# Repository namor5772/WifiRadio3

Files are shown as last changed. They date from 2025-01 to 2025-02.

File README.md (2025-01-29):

# Internet Radio

Here we describe the design, construction, programming and operation of an internet radio with a minimal one button interface based on a Raspberry Pi.
This is a relatively minor variation to WifiRadio2 (also available in this repository).
It uses a smaller older type of Raspberry Pi with the setup is more comprehensively documented.
There is a new 3D printed case that encompasses both the Raspberry Pi and the interface circuit board.

There are 7 available radio stations. One scrolls through them by successively pressing the tactile switch. The station number selected is diplayed in binary by three red 5mm LEDs. When all three LEDs are off then no station is playing (number 0). When the radio is powered off (by removing power to the Raspberry Pi) the currently streaming station is saved so that when the radio is powered on later that station resumes streaming.

## Physical design

The TinyCad design file [WifiRadio2.dsn](Hardware/WifiRadio2.dsn) for the interface circuitry is displayed below:
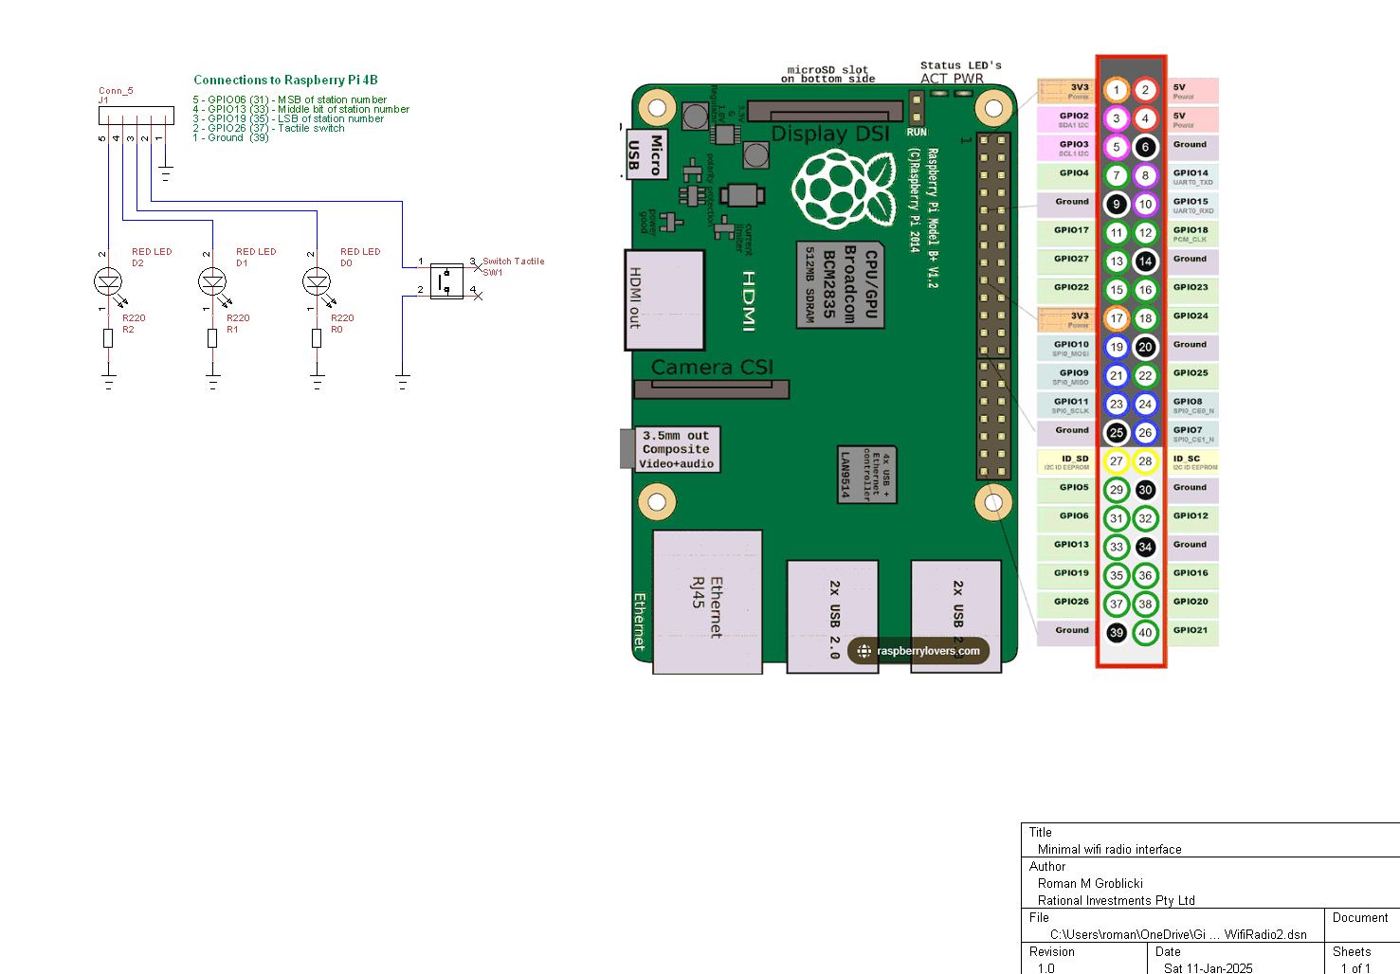
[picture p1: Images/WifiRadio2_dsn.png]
WifiRadio2.net


The resulting VeeCad file [WifiRadio2.per](Hardware/WifiRadio2.per) is displayed below:

It is obtained from the Netlist file [WifiRadio2.net](Hardware/WifiRadio2.net) generated from WifiRadio2.dsn (displayed above).
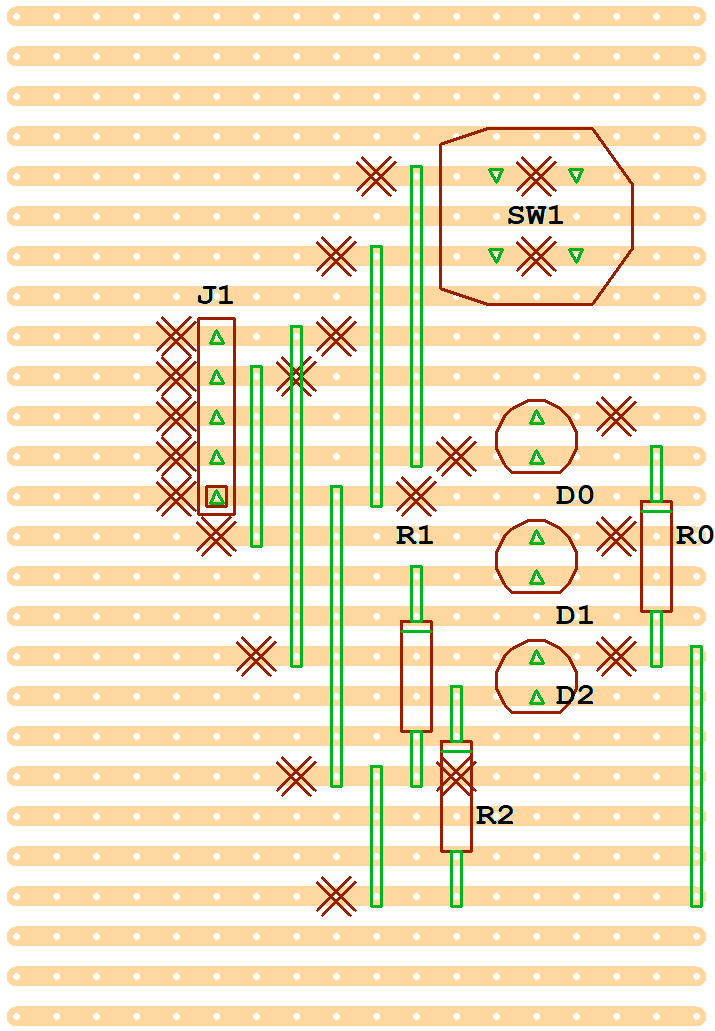
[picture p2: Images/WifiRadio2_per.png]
WifiRadio2.per


This is what the completed interface board looks like:
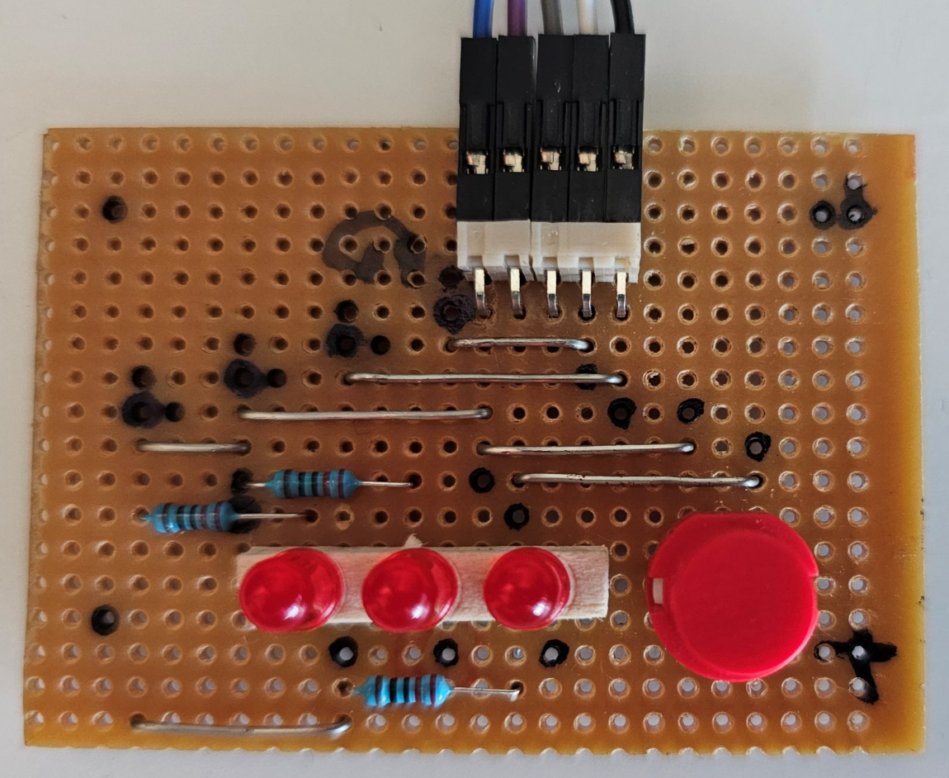
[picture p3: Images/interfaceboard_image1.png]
interfaceboard image1

Note that the LEDs are offset from the circuit board by 5mm using an appropriate piece of balsawood.
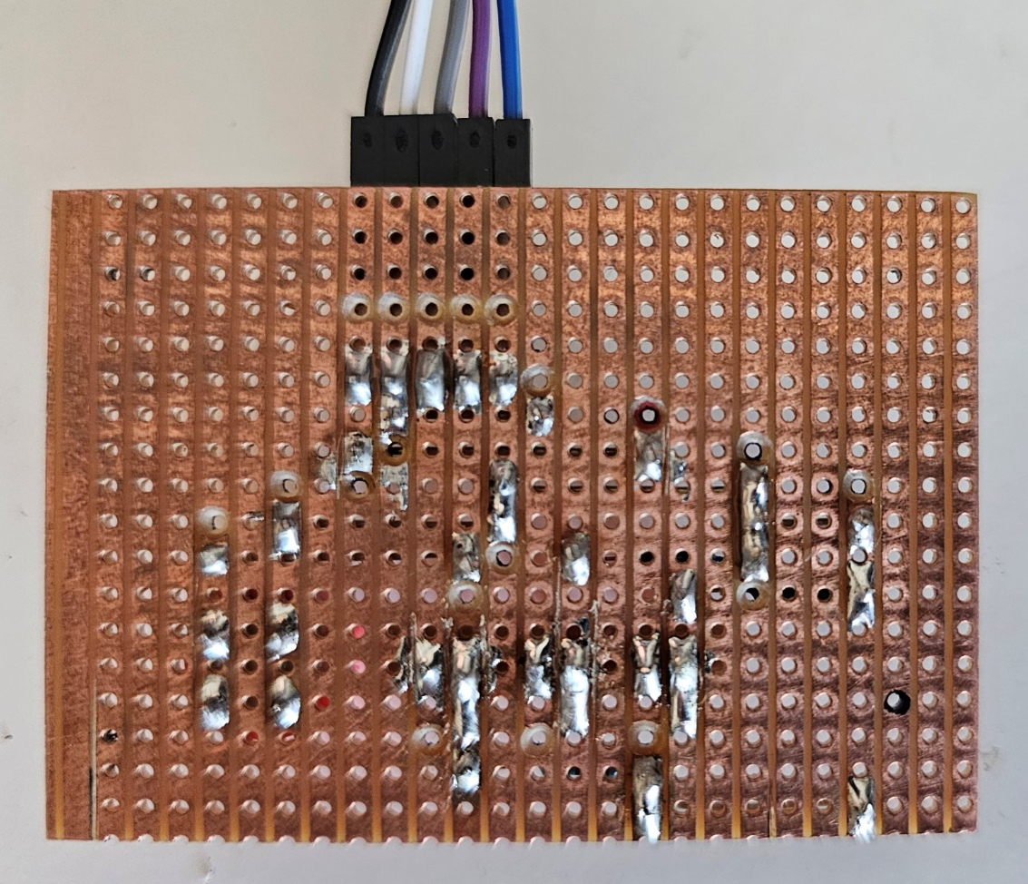
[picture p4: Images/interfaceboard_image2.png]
interfaceboard image2


## Enclosure

The interface circuit is placed in a custom 3D printed enclosure which is secured on top of the case that houses the Raspberry Pi. 5 wires connect the interface circuit to the Raspberry Pi. This is the internet radio to which stereo USB powered 3.5m audio speakers must be attached (to the underlying Raspberry Pi).

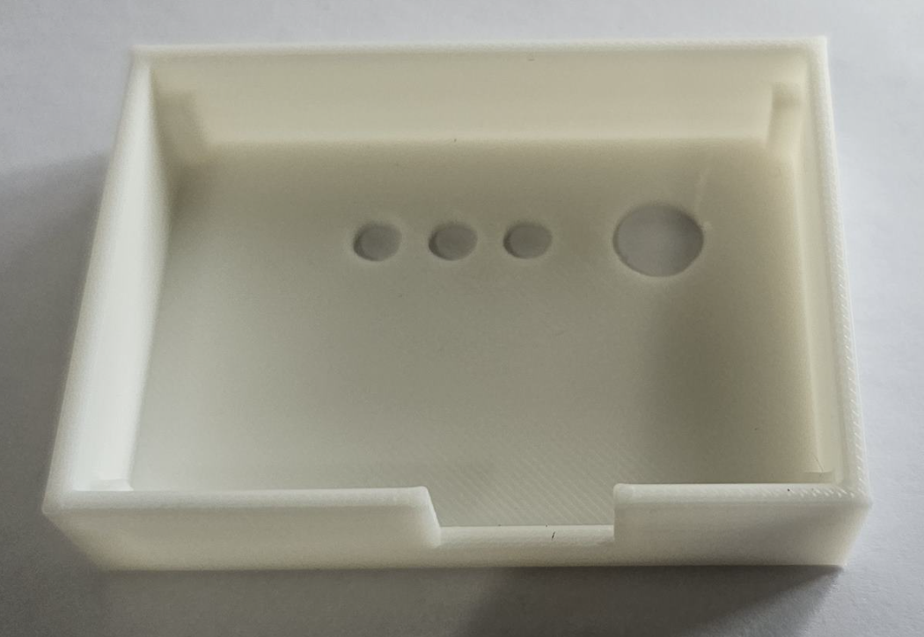
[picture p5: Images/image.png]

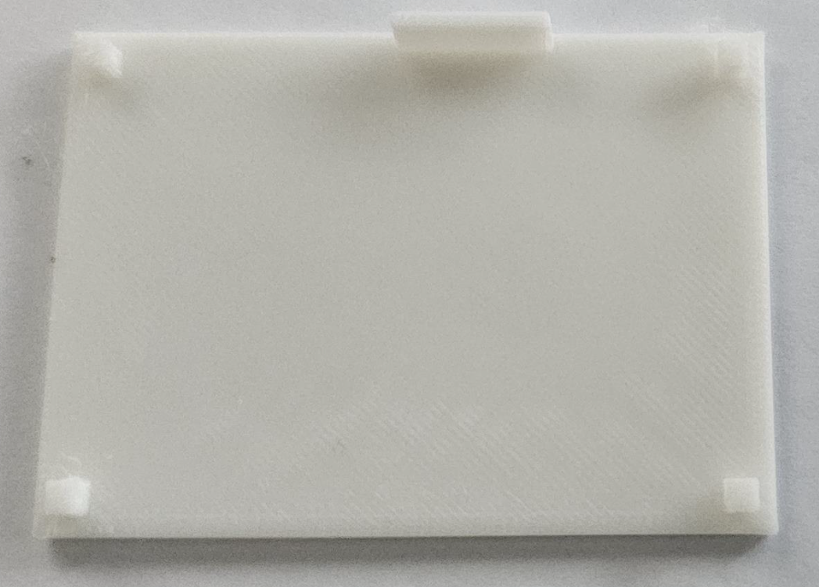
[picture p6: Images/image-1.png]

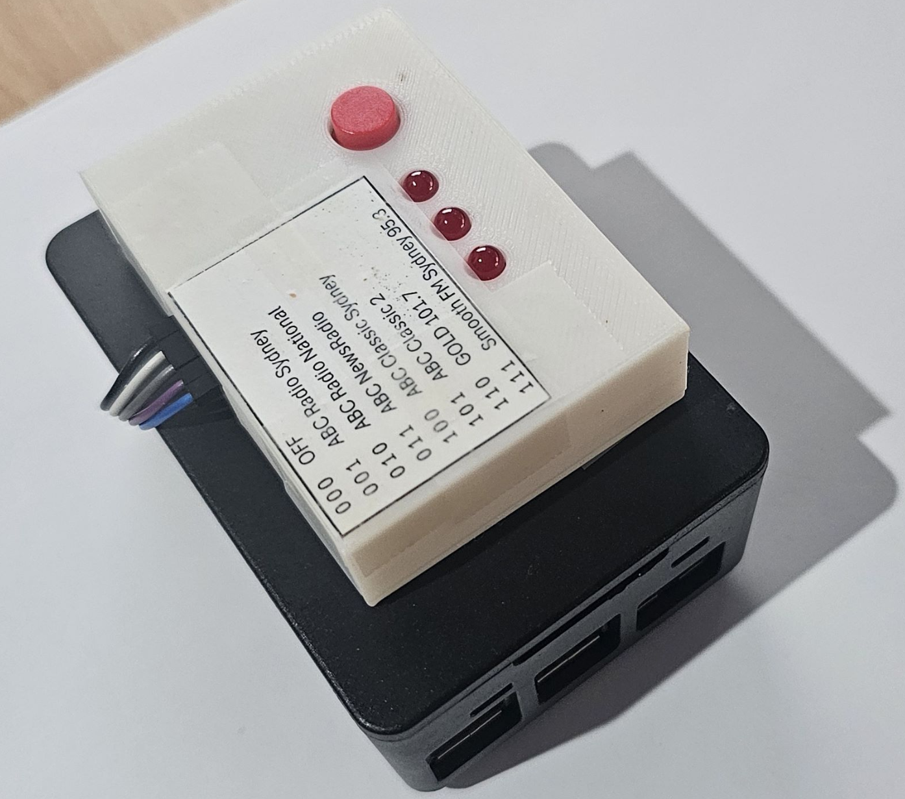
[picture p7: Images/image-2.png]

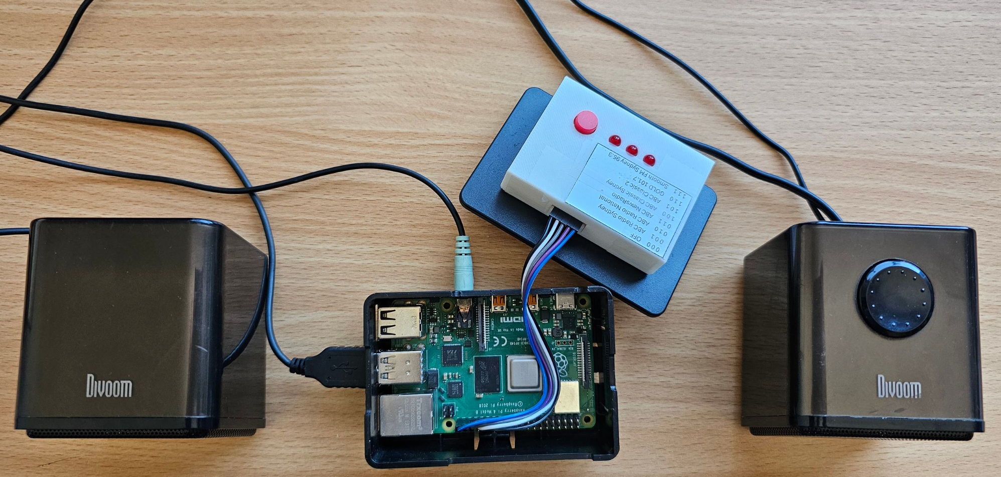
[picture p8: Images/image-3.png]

The case was designed using Blender.

The top of the case is in [WifiRadio2_BoxTop.blend](Hardware/WifiRadio2_BoxTop.blend), while the bottom is in [WifiRadio2_BoxBottom.blend](Hardware/WifiRadio2_BoxBottom.blend). To view or edit these files open them with the Blender 4.3 App in Windows 11.

To be able to 3D print the enclosure these files must be exported from the Blender App as [WifiRadio2_BoxTop.stl](Hardware/WifiRadio2_BoxTop.stl) and [WifiRadio2_BoxBottom.stl](Hardware/WifiRadio2_BoxBottom.stl) respectively.

Finally these *.stl files must be opened into the Crealty Print 6.0 Windows 11 App which creates the [WifiRadio2_BoxTop.3mf](Hardware/WifiRadio2_BoxTop.3mf) and [WifiRadio2_BoxBottom.3mf](Hardware/WifiRadio2_BoxBottom.3mfl) respectively. These contain the type of printer needed and other details of the print and are the basis for creating (by File => Export => Export Gcode...) the *.gcode files [WifiRadio2_BoxTop.gcode](Hardware/WifiRadio2_BoxTop.gcode) and [WifiRadio2_BoxBottom.gcode](Hardware/WifiRadio2_BoxBottom.gcode) respectively. These are the actual files used by the 3D Printer to do the actual printing! The files saved here are for the Crealty Ender-3 V3 SE printer with default setting for Hyper PLA.

If you have a different 3D printer you can still use the *.stl files but you will have to generate the *.gcode files yourself.

## Raspberry Pi setup

I have used a Raspberry Pi Model B Rev1.2 with 4Gb RAM, running Raspbian GNU/Linux 12 (bookworm) on a 32Gb SD card (which you will have to image).
It is configured to Boot To Desktop with Auto login, with only the Remote GPIO enabled.

Install Python3 and idle3 as well as vlc, all of which reside in the directory /usr/bin/.
In the directory /home/{username}/.config/autostart/ create a file autovlc.desktop with the contents:

```terminal
[Desktop Entry]
Type=Application
Exec=/usr/bin/idle -r /home/roman/GitHub/WifiRadio2/Radio5.py
```

This way of running the script via autostart in the GUI is because I tried to run it after boot in the Command Line Interface (CLI), however I could not make this work due to some privilage issues which made vlc unable to execute. This would have been more efficient and elegant but I just wanted to make it work.

In the directory /home/{username}/GitHub/WifiRadio2/ which you need to create place the python script Radio5.py (detailed below). You will also need to make the Wifi network automatically connect to an available access point by discovering it and inputting its password. if you move the location of this internet radio you will need to setup another wifi connection by accessing the Raspbewrry Pi's GUI with an attached mouse, keyboard and screen! 

## Software

The radio is implemented in software by a python script [Radio5.py](Radio5.py) that auto starts through the Python IDLE shell when the the GUI becomes active. The audio streaming uses cvlc. A valid wifi connection is assumed to be available and automatically enabled when the Raspberry Pi is powered on.

```python
# all part of the Python standard libraries, with RPI.GPIO pre installed as part of the Raspian os
import subprocess
import time
import RPi.GPIO as GPIO
import os;    

# Get the directory where the script is located
script_directory = os.path.dirname(os.path.abspath(__file__))

# Create the full filepath to the saved radio station file
filename = 'savedRadioStation.txt'
filepath = os.path.join(script_directory, filename)
print(f'The file {filepath} stores the last streamed station number.')

# Use BCM GPIO numbering 
GPIO.setmode(GPIO.BCM)

# Define the 4 Raspberry Pi pins that go to the interface circuit board
# Ground is not included
button_pin = 26
led0_pin = 19
led1_pin = 13
led2_pin = 6

# Setup the pins
GPIO.setup(button_pin, GPIO.IN, pull_up_down=GPIO.PUD_UP)
GPIO.setwarnings(False)
GPIO.setup(led0_pin, GPIO.OUT)
GPIO.setup(led1_pin, GPIO.OUT)
GPIO.setup(led2_pin, GPIO.OUT)

# setup the leds to be initially all off
GPIO.output(led0_pin,GPIO.LOW)
GPIO.output(led1_pin,GPIO.LOW)
GPIO.output(led2_pin,GPIO.LOW)

# 2D array of radio station information in [short name, long name, url] format
# clearly this can be varied if you wish to listen to different 7 stations
aStation = [
    ["2LRW","ABC Radio Sydney","https://live-radio01.mediahubaustralia.com/2LRW/mp3/"],
    ["5LRW","ABC Radio National","https://live-radio01.mediahubaustralia.com/2RNW/mp3/"],
    ["PBW","ABC NewsRadio","https://live-radio01.mediahubaustralia.com/PBW/mp3/"],
    ["2FMW","ABC Classic Sydney","https://live-radio01.mediahubaustralia.com/2FMW/mp3/"],
    ["FM2W","ABC Classic 2","https://live-radio01.mediahubaustralia.com/FM2W/mp3/"],
    ["WSFM","GOLD 101.7","https://playerservices.streamtheworld.com/api/livestream-redirect/ARN_WSFM.mp3"],
    ["SMOOTH953","Smooth FM Sydney 95.3","https://playerservices.streamtheworld.com/api/livestream-redirect/SMOOTH953.mp3"]
]

# some utility global variables
vlc_path = "/usr/bin/cvlc" # full path to cvlc, it is installed together with vlc
Running = False # flag True if radio station is streaming
nStation = 0 # station number (0 is the "no radio streaming" station)
startup = True # True when radio initially powered up 

print("Radio stream interface")

while True:

    if ((GPIO.input(button_pin) == GPIO.LOW) or (startup)):
        time.sleep(0.2) # pathetic debouncing code

        if (startup):
            # load saved station number from file when radio powered up
            try:
                with open(filepath, 'r') as file:
                    nStation = int(file.read())
            except FileNotFoundError:
                print(f'Error: The file {filepath} does not exist.')
                nStation = 0
        else:
            # increment station number modulo 8 when button pressed
            if nStation == 7:
                nStation = 0
            else:
                nStation = nStation +1

            # save station number to file (if radio powered off when playing this station)
            with open(filepath, 'w') as file:
                file.write(str(nStation))

        # display the station number in binary
        bit0 = (nStation >> 0) & 1 # LSB
        bit1 = (nStation >> 1) & 1 # middle bit
        bit2 = (nStation >> 2) & 1 # MSB
        GPIO.output(led0_pin,bit0)
        GPIO.output(led1_pin,bit1)
        GPIO.output(led2_pin,bit2)
        print("Button pressed, Station: ",nStation)    

        if nStation > 0:
            stream_url = aStation[nStation-1][2]
            stream_longName = aStation[nStation-1][1]

        if nStation == 0:
            if Running:    
                process.terminate()
            Running = False
            print("No streaming")

        elif nStation == 1:
            # started new process, but no need to terminate previous one since already terminated
            process = subprocess.Popen([vlc_path, stream_url])
            Running = True
            print("Started streaming radio station: " + stream_longName)

        else:
            if (not startup):
                # need to terminate current process, before starting new one
                process.terminate()
                
            process = subprocess.Popen([vlc_path, stream_url])
            Running = True
            print("Started streaming radio station: " + stream_longName)

        startup = False   

```
## List of parts

Pricing and availability as of 26-Jan-2025. Total cost is $250.57, but clearly some of the items will be usable in many other projects or you will already have them. The pro rata cost is __$209.11__

You will also need a soldering iron and solder, some two sided tape for attaching the circuit enclosure on top of the Raspberry Pi case as well as a printer to print the station legend for taping/sticking to the top of the enclosure. 

| Qty | Product | Description | AUD Cost | Comment | Designator |
| --- | --- | --- | --- | --- | --- |
| 1 | [RPI4-MODBP-4GB](https://au.element14.com/raspberry-pi/rpi4-modbp-4gb/raspberry-pi-4-model-b-4gb/dp/3051887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) | SBC, [Raspberry Pi4 B 4GB](Images/RPI4B.png), BCM2711, ARM Cortex-A72, 4GB RAM, MicroSD, Linux, Wifi, 2x micro HDMI | $92.65 | The brains of this project with this [datasheet](Hardware/4170044.pdf)  | connected via J1 |
| 1 | [XC4992](https://jaycar.com.au/p/XC4992) | 32GB Class 10 microSDHC [Card](Images/Card.png) | $12.95 | For Raspberry Pi OS and storage | |
| 1 | [PH-102475](https://raspberry.piaustralia.com.au/products/highpi-raspberry-pi-4-model-b-case) | HighPi Raspberry Pi 4 Model B [Case](Images/Case.png) | $32.12 | could use other cases | |
| 1 | [HP9544](https://jaycar.com.au/p/HP9544) | PC Boards Vero Type [Strip](Images/Strip.png) - 95mm x 305mm | $15.50 | Contains the circuit | $4.00 cost used|
| 3 | [ZD0150](https://jaycar.com.au/p/ZD0150) | Red 5mm [LED](Images/LED.png) 8mcd Round Diffused | $1.20 | indicate status in binary | D0, D1, D2 |
| 1 | [SP0720](https://jaycar.com.au/p/SP0720) | Red Snap Action Keyboard [Switch](Images/Switch.png) - PCB Mount | $1.45 | The only input item | SW1 |
| 1 | [RR0556](https://jaycar.com.au/p/RR0556) | 220 Ohm 0.5 Watt Metal Film [Resistors](Images/Resistor.png) - Pack of 8 (only need 3) | $0.85 | Current limiting for LEDs | R0, R1, R2 - $0.32 cost used|
| 1 | [HM3422](https://jaycar.com.au/p/HM3422) | 2 Pin 0.1in 90 Degree Locking [Header](Images/Header2.png) - 2.54mm Pitch - Single | $0.30 | connector to RPi | part of J1 |
| 1 | [HM3423](https://jaycar.com.au/p/HM3423) | 3 Pin 0.1in 90 Degree Locking [Header](Images/Header3.png) - 2.54mm Pitch - Single | $0.40 | connector to RPi | part of J1 |
| 1 | [WW4030](https://jaycar.com.au/p/WW4030) | Tinned Copper [Wire](Images/Wire.png) - 100 gram Roll | $19.95 | for wiring up above Vero board | $0.80 cost used|
| 1 | [WC6026](https://jaycar.com.au/p/WC6026) | 150mm Socket to Socket Jumper [Leads](Images/Leads.png) - 40 Piece | $11.75 | 5 wires to connect Vero Board to Raspberry Pi | connects to J1 - $1.47 cost used|
| 1 | [XC5191](https://jaycar.com.au/p/XC5191) | USB Powered PC [Speakers](Images/Speakers.png) | $19.75 | Any if USB powered & 3.5mm input | |
| 1 | [MP3449](https://jaycar.com.au/p/MP3449) | Mains USB Mini Power [Adaptor](Images/Adaptor.png) - 2.4A | $26.95 | to Power Raspberry Pi | |
| 1 | [WC7900](https://jaycar.com.au/p/WC7900) | USB Type-C to USB 2.0 A Male [Cable](Images/Cable.png) 1.8m | $14.75 | to Power Raspberry Pi | |

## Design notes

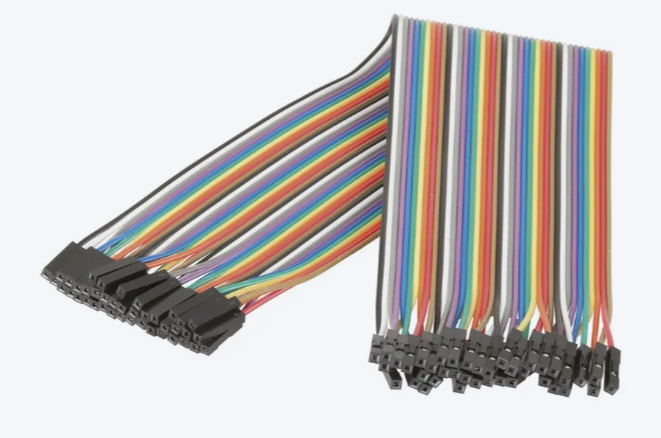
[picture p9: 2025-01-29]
Images/Leads.png

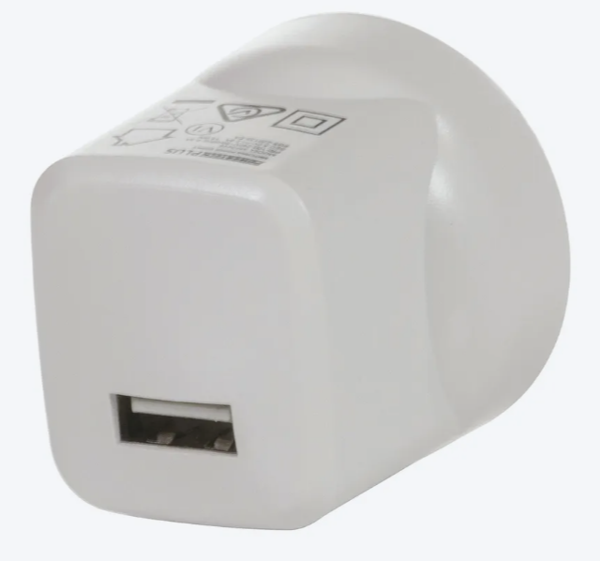
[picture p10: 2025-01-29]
Images/Adaptor copy.png

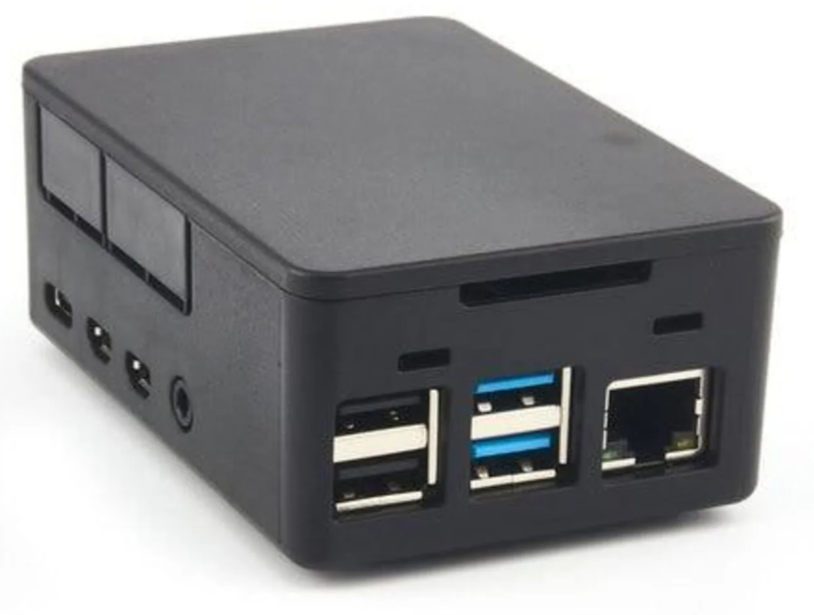
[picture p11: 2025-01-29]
Images/Case copy.png

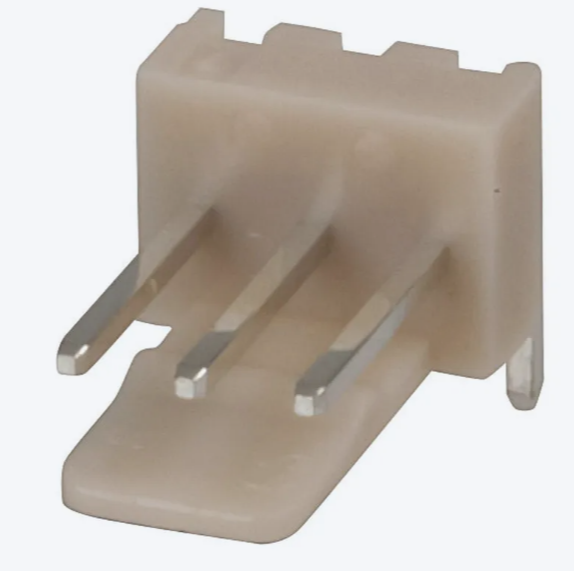
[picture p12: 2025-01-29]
Images/Header3.png

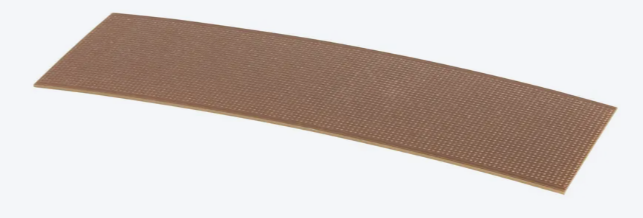
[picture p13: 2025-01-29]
Images/Strip.png

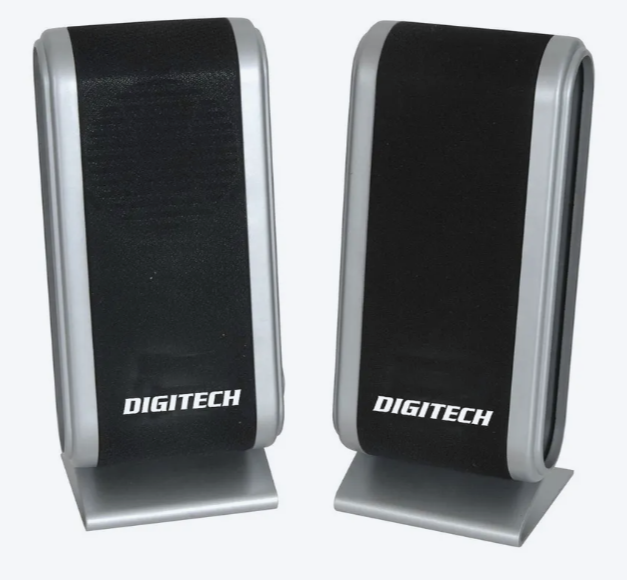
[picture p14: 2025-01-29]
Images/Speakers.png

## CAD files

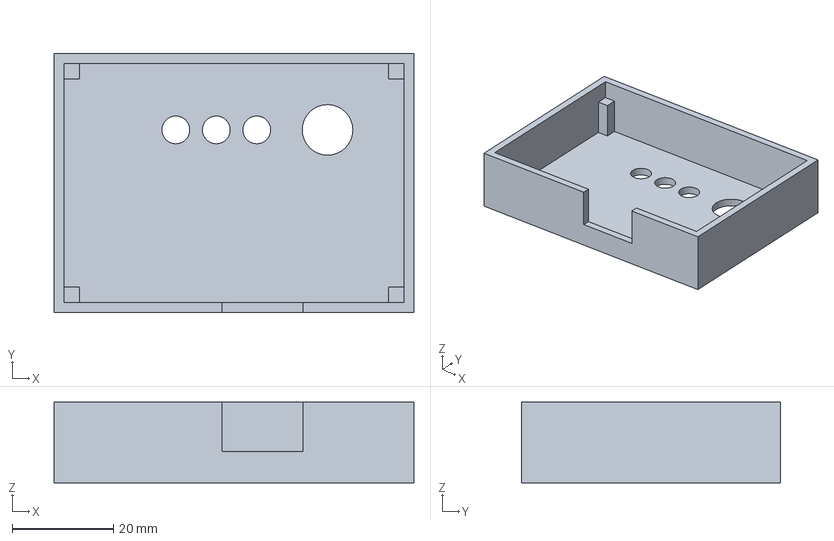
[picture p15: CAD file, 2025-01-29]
Hardware/WifiRadio2_BoxTop.3mf
71.2 x 51.2 x 16.0 mm

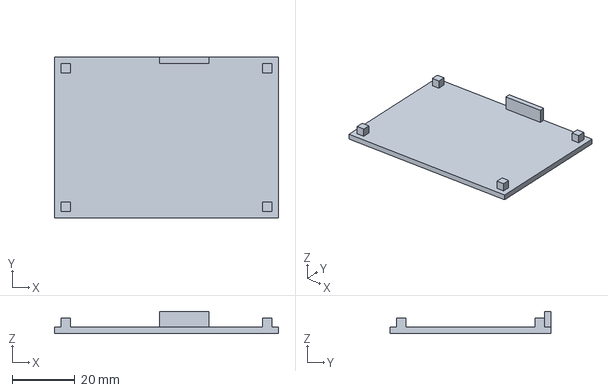
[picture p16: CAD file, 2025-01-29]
Hardware/WifiRadio2_BoxBottom.3mf
71.2 x 51.2 x 7.00 mm

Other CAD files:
Hardware/WifiRadio2_BoxBottom.blend
Hardware/WifiRadio2_BoxBottom.stl
Hardware/WifiRadio2_BoxTop.blend
Hardware/WifiRadio2_BoxTop.stl

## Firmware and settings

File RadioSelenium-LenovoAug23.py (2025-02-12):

import subprocess
import inspect
import tkinter as tk
import time
import urllib.request
import requests

from PIL import Image, ImageTk
from tkinter import ttk
from bs4 import BeautifulSoup
from selenium import webdriver
from selenium.webdriver.firefox.options import Options
from selenium.webdriver.common.by import By
from selenium.common.exceptions import NoSuchElementException
from selenium.webdriver.common.keys import Keys
from selenium.webdriver.common.action_chains import ActionChains
from selenium.webdriver.support.ui import WebDriverWait
from selenium.webdriver.support import expected_conditions as EC

# Create an instance of FirefoxOptions
firefox_options = Options()
#firefox_options.add_argument("-headless")  # Ensure this argument is correct
browser = webdriver.Firefox(options=firefox_options)

image_path = r"C:\Users\grobl\OneDrive\GitRepos\WifiRadio3\Images\logo.png"
image2_path = r"C:\Users\grobl\OneDrive\GitRepos\WifiRadio3\Images\presenter.jpg"



def Suck_ABC(br,sPath):
    br.refresh()
    br.get(sPath)
    time.sleep(3)
    be = br.find_element(By.TAG_NAME, 'body')
    be.send_keys(Keys.TAB)
    be.send_keys(Keys.ENTER)
    be.send_keys(Keys.TAB)
    be.send_keys(Keys.TAB)

    be.send_keys(Keys.TAB)
    be.send_keys(Keys.TAB)
    be.send_keys(Keys.TAB)
    be.send_keys(Keys.TAB)
    be.send_keys(Keys.TAB)
    be.send_keys(Keys.TAB)
    be.send_keys(Keys.TAB)
    be.send_keys(Keys.TAB)
    be.send_keys(Keys.TAB)
    be.send_keys(Keys.TAB)
    be.send_keys(Keys.TAB)
    be.send_keys(Keys.TAB)
    be.send_keys(Keys.TAB)
    be.send_keys(Keys.TAB)
    be.send_keys(Keys.TAB)

    # Use JavaScript to get the currently focused (active) element
    active_element = br.execute_script("return document.activeElement")

    # Retrieve various attributes of the active element
    element_tag_name = active_element.tag_name
    element_id = active_element.get_attribute('id')
    element_class = active_element.get_attribute('class')
    element_name = active_element.get_attribute('name')
    element_value = active_element.get_attribute('value')
    element_inner_html = active_element.get_attribute('innerHTML')

    # Parse the innerHTML with BeautifulSoup
    soup = BeautifulSoup(element_inner_html, 'lxml')

    # Find all elements with data-component="KeyboardFocus"
    focused_elements = soup.find_all(attrs={"data-component": "KeyboardFocus"})

    # Extract and print the text content of these elements
    for element in focused_elements:
        print(element.text)

    be.send_keys(Keys.ENTER)
    time.sleep(1)
    be = br.find_element(By.TAG_NAME, 'body')

    for _ in range(14):
        be.send_keys(Keys.TAB)
    be.send_keys(Keys.ENTER)




# START ***** Functions that stream radio stations *****

# ALL GOOD
def Radio1(br,Num,sPath):
    br.get(sPath)
    time.sleep(1)
    be = br.find_element(By.TAG_NAME, 'body')
    for _ in range(Num):
        be.send_keys(Keys.TAB)
    be.send_keys(Keys.ENTER)
    time.sleep(1)
    # Find song details
    ht = be.get_attribute('innerHTML')
    soup = BeautifulSoup(ht, 'lxml')
    fe = soup.find(attrs={"class": "playingNow"})
    if fe is not None:
        fe2 = fe.get_text(separator="*", strip=True)
    else:
        fe2 = "No specific item playing"
    return fe2

# ALL GOOD
def Radio2(br,Num,sPath):
    br.get(sPath)
    time.sleep(1)
    be = br.find_element(By.TAG_NAME, 'body')
    for _ in range(3):
        be.send_keys(Keys.TAB)
    be.send_keys(Keys.ENTER)
    for _ in range(4):
        be.send_keys(Keys.UP)
    for _ in range(Num):
        be.send_keys(Keys.DOWN)
    be.send_keys(Keys.ENTER)
    for _ in range(3):
        be.send_keys(Keys.TAB)
    be.send_keys(Keys.ENTER)
    time.sleep(1)

  # get station logo
    # Display the station logo as given in the image_path2 variable below
    image_path2 = r"C:\Users\grobl\OneDrive\GitRepos\WifiRadio3\Images\ABC_Radio_National.png"
    image = Image.open(image_path2)
    scaled_image = image.resize((90, 90))  # Adjust the size as needed
    photo = ImageTk.PhotoImage(scaled_image)
    label.config(image=photo)
    label.image = photo  # Keep a reference to avoid garbage collection

  # get presenter image
    img2_element = be.find_element(By.XPATH, '/html/body/div[1]/div/div/div/main/div[1]/div/div/header/div/div/img')
    img2_url = img2_element.get_attribute("src")
    urllib.request.urlretrieve(img2_url, image2_path)

    # Display the station presenter as given in the image2_path global variable
    image2 = Image.open(image2_path)
    width2, height2 = image2.size;
    print(f"width: {width2}, height: {height2}")
    scaled_image2 = image2.resize((int(135*width2/height2), 135))  # Adjust the size as needed
    photo2 = ImageTk.PhotoImage(scaled_image2)
    label2.config(image=photo2)
    label2.image = photo2  # Keep a reference to avoid garbage collection
    label2.place(x=339, y=107)  # Adjust the position
    
  # Find stream details
    ht = be.get_attribute('innerHTML')
    soup = BeautifulSoup(ht, 'lxml')
    fe = soup.find(attrs={"class": "view-live-now popup"})
    if fe is not None:
        fe2 = fe.get_text(separator="*", strip=True)
    else:
        fe2 = "No specific item playing"
  # Remove irrelevant info, starting with [*.*More]
    sub = "*.*More"
    pos = fe2.find(sub)
    if pos != -1:
        fe2 = fe2[:pos]
    return fe2


# ALL GOOD
def Radio3(br,Num,sPath):
    br.get(sPath)
    time.sleep(1)
    be = br.find_element(By.TAG_NAME, 'body')
    for _ in range(5):
        be.send_keys(Keys.TAB)
    be.send_keys(Keys.ENTER)
    for _ in range(4):
        be.send_keys(Keys.UP)
    for _ in range(Num):
        be.send_keys(Keys.DOWN)
    be.send_keys(Keys.ENTER)
    for _ in range(3):
        be.send_keys(Keys.TAB)
    be.send_keys(Keys.ENTER)
    time.sleep(1)

    stack = inspect.stack()
    print("--")
    print(inspect.currentframe().f_code.co_name)
    print(stack[0].function)
    print(stack[1].function)
    print(stack[2].function)
    print(stack[3].function)
    print("--")
    
  # get station logo
    # Display the station logo as given in the image_path2 variable below
    image_path2 = r"C:\Users\grobl\OneDrive\GitRepos\WifiRadio3\Images\ABC_triple_j.png"
    image = Image.open(image_path2)
    scaled_image = image.resize((90, 90))  # Adjust the size as needed
    photo = ImageTk.PhotoImage(scaled_image)
    label.config(image=photo)
    label.image = photo  # Keep a reference to avoid garbage collection

  # get program image
    try:      
        img2_element = be.find_element(By.XPATH, '/html/body/div[1]/div/div/div/main/div[1]/div/div/div[3]/div[1]/div/div[2]/div[2]/img')
        img2_url = img2_element.get_attribute("src")
        #response = requests.head(img2_url)
        image2_path = r"C:\Users\grobl\OneDrive\GitRepos\WifiRadio3\Images\presenter.jpg"
        urllib.request.urlretrieve(img2_url, image2_path)
    except NoSuchElementException:
        print("Image element not found on the webpage.")            
        # Display a blank image
        image2_path = r"C:\Users\grobl\OneDrive\GitRepos\WifiRadio3\Images\Blank.png"
    # Display the program image as given in the image2_path global variable
    image2 = Image.open(image2_path)
    width2, height2 = image2.size;
    print(f"width: {width2}, height: {height2}")
    crop_box2 = (width2-height2,0,width2,height2)
    cropped_image2 = image2.crop(crop_box2)
    scaled_image2 = cropped_image2.resize((135, 135))  # Adjust the size as needed
    photo2 = ImageTk.PhotoImage(scaled_image2)
    label2.config(image=photo2)
    label2.image = photo2  # Keep a reference to avoid garbage collection
    label2.place(x=455, y=107)  # Adjust the position

  # Find program details
    ht = be.get_attribute('innerHTML')
    soup = BeautifulSoup(ht, 'lxml')
    fe = soup.find(attrs={"class": "view-live-now popup"})
    if fe is not None:
        fe1 = fe.get_text(separator="*", strip=True)
    else:
        fe1 = "None"
    # Remove irrelevant info, starting with [*More]
    sub = "*More"
    pos = fe1.find(sub)
    if pos != -1:
        fe1 = fe1[:pos]
    # find song details    
    fe = soup.find(attrs={"class": "playingNow"})
    if fe is not None:
        fe2 = fe.get_text(separator="*", strip=True)
    else:
        fe2 = "No specific item playing"
    fe3 = fe1+"*"+fe2
    return fe3


# ALL GOOD
def Radio4(br,sPath):
    br.get(sPath)
    time.sleep(1)
    be = br.find_element(By.TAG_NAME, 'body')
    be.send_keys(Keys.TAB)
    be.send_keys(Keys.ENTER)
    for _ in range(3):
        be.send_keys(Keys.TAB)
        
  # adjust amount of tabbing depending on where you end up!
    focused_element = br.execute_script("return document.activeElement")
    if not("Button_btn___qFSk" in focused_element.get_attribute('class')):
           be.send_keys(Keys.SHIFT,Keys.TAB)
           print("ADJUSTED TAB")
    be.send_keys(Keys.ENTER)
    be.send_keys(Keys.SHIFT,Keys.TAB)
    be.send_keys(Keys.TAB)
    be.send_keys(Keys.TAB)
    time.sleep(3)
    
  # get station logo
    img_element = be.find_element(By.XPATH, '/html/body/div[1]/div/div/div[1]/div/main/div[1]/div/div/div/a/div/img')
    img_url = img_element.get_attribute("src")
    urllib.request.urlretrieve(img_url, image_path)

    # Display the station logo as given in the image_path global variable
    image = Image.open(image_path)
    scaled_image = image.resize((90, 90))  # Adjust the size as needed
    photo = ImageTk.PhotoImage(scaled_image)
    label.config(image=photo)
    label.image = photo  # Keep a reference to avoid garbage collection
   
  # get presenter image
    img2_element = be.find_element(By.XPATH, '/html/body/div[1]/div/div/div[1]/div/main/div[1]/div/div/div/div[1]/div[1]/div/div/div/img')
    img2_url = img2_element.get_attribute("src")
    urllib.request.urlretrieve(img2_url, image2_path)

    # Display the station presenter as given in the image2_path global variable
    # cropping and scaling
    image2 = Image.open(image2_path)
    width2, height2 = image2.size;
    print(f"width: {width2}, height: {height2}")
    crop_box2 = (width2-height2,0,width2,height2)
    cropped_image2 = image2.crop(crop_box2)
    scaled_image2 = cropped_image2.resize((135, 135))  # Adjust the size as needed
    photo2 = ImageTk.PhotoImage(scaled_image2)
    label2.config(image=photo2)
    label2.image = photo2  # Keep a reference to avoid garbage collection
    label2.place(x=155, y=107)  # Adjust the position
    
  # Find live program details
    ht = be.get_attribute('innerHTML')
    soup = BeautifulSoup(ht, 'lxml')
    fe = soup.find(attrs={"class": "LiveAudioPlayer_body__y6nYe"})
    if fe is not None:
        fe2 = fe.get_text(separator="*", strip=True)
    else:
        fe2 = "No item playing"
    # Remove irrelevant info [*-]
    sub = "*-"
    fe3 = fe2.replace(sub,"")
    
  # Find live program synopsis
    fe = soup.find(attrs={"class": "LiveAudioSynopsis_content__DZ6E7"})
    if fe is not None:
        fe2 = fe.get_text(separator="*", strip=True)
    else:
        fe2 = "No Description"
        
  # Return info text      
    fe3 = fe3+"* * *"+fe2
    return fe3


# ALL GOOD    
def Radio5(br,Num,sPath):
    browser.get(sPath)
    time.sleep(1)
    be = br.find_element(By.TAG_NAME, 'body')
    be.send_keys(Keys.TAB)
    be.send_keys(Keys.ENTER)
    for _ in range(Num):
        be.send_keys(Keys.TAB)
    be.send_keys(Keys.ENTER)
    be.send_keys(Keys.TAB)
    be.send_keys(Keys.TAB)
    time.sleep(1)

  # get station logo
    img_element = be.find_element(By.XPATH, '/html/body/div[1]/div/div/div[1]/div/main/div[1]/div/div/div/a/div/img')
    img_url = img_element.get_attribute("src")
    urllib.request.urlretrieve(img_url, image_path)

    # Display the station logo as given in the image_path global variable
    image = Image.open(image_path)
    scaled_image = image.resize((90, 90))  # Adjust the size as needed
    photo = ImageTk.PhotoImage(scaled_image)
    label.config(image=photo)
    label.image = photo  # Keep a reference to avoid garbage collection

  # get presenter image
    img2_element = be.find_element(By.XPATH, '/html/body/div[1]/div/div/div[1]/div/main/div[1]/div/div/div/div[1]/div[1]/div/div/div/img')
    img2_url = img2_element.get_attribute("src")
    urllib.request.urlretrieve(img2_url, image2_path)

    # Display the station presenter as given in the image2_path global variable
    # cropping and scaling
    image2 = Image.open(image2_path)
    width2, height2 = image2.size;
    print(f"width: {width2}, height: {height2}")
    crop_box2 = (width2-height2,0,width2,height2)
    cropped_image2 = image2.crop(crop_box2)
    scaled_image2 = cropped_image2.resize((135, 135))  # Adjust the size as needed
    photo2 = ImageTk.PhotoImage(scaled_image2)
    label2.config(image=photo2)
    label2.image = photo2  # Keep a reference to avoid garbage collection
    label2.place(x=445, y=107)  # Adjust the position

    # Find song details
    ht = be.get_attribute('innerHTML')
    soup = BeautifulSoup(ht, 'lxml')
    fe = soup.find(attrs={"class": "LiveAudioPlayer_body__y6nYe"})
    if fe is not None:
        fe2 = fe.get_text(separator="*", strip=True)
    else:
        fe2 = "No item playing"
    # Remove irrelevant info [*-]
    sub = "*-"
    fe3 = fe2.replace(sub,"")
    return fe3


def Radio6(br,sPath):
    br.get(sPath)
    time.sleep(1)
    be = br.find_element(By.TAG_NAME, 'body')
    for _ in range(3):
        be.send_keys(Keys.TAB)
    be.send_keys(Keys.ENTER)
    time.sleep(1)
    # Find program details
    ht = be.get_attribute('innerHTML')
    soup = BeautifulSoup(ht, 'lxml')
    fe = soup.find(attrs={"class": "view-live-now popup"})
    if fe is not None:
        fe1 = fe.get_text(separator="*", strip=True)
    else:
        fe1 = "None"
    # Remove irrelevant info, starting with [*More]
    sub = "*More"
    pos = fe1.find(sub)
    if pos != -1:
        fe1 = fe1[:pos]
    # Find song details     
    fe = soup.find(attrs={"class": "playingNow"})
    if fe is not None:
        fe2 = fe.get_text(separator="*", strip=True)
    else:
        fe2 = "No specific item playing"
    fe3 = fe1+"*"+fe2
    return fe3

def Radio7(br,Num,sPath):
    br.get(sPath)
    time.sleep(1)
    be = br.find_element(By.TAG_NAME, 'body')
    be.send_keys(Keys.TAB)
    be.send_keys(Keys.ENTER)
    for _ in range(11):
        be.send_keys(Keys.TAB)
    if Num==0:
        be.send_keys(Keys.ENTER)
    elif Num==1:
        be.send_keys(Keys.TAB)
        be.send_keys(Keys.ENTER)
    else: # if Num==2
        be.send_keys(Keys.TAB)
        be.send_keys(Keys.TAB)
        be.send_keys(Keys.ENTER)
        be.send_keys(Keys.ENTER)
    # Find program details
    ht = be.get_attribute('innerHTML')
    time.sleep(1)
    soup = BeautifulSoup(ht, 'lxml')
    if Num==0:
        xid="abc-:rb:-item-0"
    elif Num==1:
        xid="abc-:rb:-item-1"
    else: # if Num==2
        xid="abc-:rb:-item-2"
    fe = soup.find(attrs={"id": xid})
    if fe is not None:
        fe2 = fe.get_text(separator="*", strip=True)
    else:
        fe2 = "None"
    # Remove irrelevant info, starting with [*.*More]
    sub = "*Stop"
    pos = fe2.find(sub)
    if pos != -1:
        fe2 = fe2[:pos]
    else:
        sub = "*Listen"
        pos = fe2.find(sub)
        if pos != -1:
            fe2 = fe2[:pos]
    return fe2



def Smooth(br,ix,iy,sPath):
 #   print(inspect.stack()[1].function)
    br.refresh()
    br.get(sPath)
    time.sleep(3)
    window_size = br.get_window_size()
    print(f"Window size: width = {window_size['width']}, height = {window_size['height']}")
    actions = ActionChains(br)
    actions.move_by_offset(650, 10).click().perform()
    window_size = br.get_window_size()
    
    print(f"Window size: width = {window_size['width']}, height = {window_size['height']}")
    time.sleep(1)
    actions = ActionChains(br)
    actions.move_by_offset(ix,iy).click().perform()
    time.sleep(10)

def Smooth2(br,sPath):
 #   print(inspect.stack()[1].function)
    br.refresh()
    br.get(sPath)
    time.sleep(3)
    window_size = br.get_window_size()
    actions = ActionChains(br)
    actions.move_by_offset(650, 900).click().perform()
    window_size = br.get_window_size()
    time.sleep(10)



def iHeart(br,sPath):
 #   print(inspect.stack()[1].function)
    br.refresh()
    br.get(sPath)
    time.sleep(3)
    window_size = br.get_window_size()
    #print(f"Window size: width = {window_size['width']}, height = {window_size['height']}")
    actions = ActionChains(br)
    actions.move_by_offset(301, 256).click().perform()
    time.sleep(10)

    

def ABC_Radio_Sydney_NSW():
    return Radio4(browser,"https://www.abc.net.au/listen/live/sydney")

def ABC_Broken_Hill_NSW():
    return Radio4(browser,"https://www.abc.net.au/listen/live/brokenhill")

def ABC_Central_Coast_NSW():
    return Radio4(browser,"https://www.abc.net.au/listen/live/centralcoast")

def ABC_Central_West_NSW():
    return Radio4(browser,"https://www.abc.net.au/listen/live/centralwest")

def ABC_Coffs_Coast_NSW():
    return Radio4(browser,"https://www.abc.net.au/listen/live/coffscoast")

def ABC_Illawarra_NSW():
    return Radio4(browser,"https://www.abc.net.au/listen/live/illawarra")

def ABC_Mid_North_Coast_NSW():
    return Radio4(browser,"https://www.abc.net.au/listen/live/midnorthcoast")

def ABC_New_England_North_West_NSW():
    return Radio4(browser,"https://www.abc.net.au/listen/live/newengland")

def ABC_Newcastle_NSW():
    return Radio4(browser,"https://www.abc.net.au/listen/live/newcastle")

def ABC_North_Coast_NSW():
    return Radio4(browser,"https://www.abc.net.au/listen/live/northcoast")

def ABC_Riverina_NSW():
    return Radio4(browser,"https://www.abc.net.au/listen/live/riverina")

def ABC_South_East_NSW():
    return Radio4(browser,"https://www.abc.net.au/listen/live/southeastnsw")

def ABC_Upper_Hunter_NSW():
    return Radio4(browser,"https://www.abc.net.au/listen/live/upperhunter")

def ABC_Western_Plains_NSW():
    return Radio4(browser,"https://www.abc.net.au/listen/live/westernplains")

def ABC_Radio_Canberra_ACT():
    return Radio4(browser,"https://www.abc.net.au/listen/live/canberra")

def ABC_Radio_Darwin_NT():
    return Radio4(browser,"https://www.abc.net.au/listen/live/darwin")

def ABC_Alice_Springs_NT():
    return Radio4(browser,"https://www.abc.net.au/listen/live/alicesprings")

def ABC_NewsRadio():
    return Radio4(browser,"https://www.abc.net.au/listen/live/news")


    
def ABC_Radio_National_LIVE():
    return Radio2(browser,0,"https://www.abc.net.au/listen/live/radionational")

def ABC_Radio_National_QLD():
    return Radio2(browser,1,"https://www.abc.net.au/listen/live/radionational")

def ABC_Radio_National_WA():
    return Radio2(browser,2,"https://www.abc.net.au/listen/live/radionational")

def ABC_Radio_National_SA():
    return Radio2(browser,3,"https://www.abc.net.au/listen/live/radionational")

def ABC_Radio_National_NT():
    return Radio2(browser,4,"https://www.abc.net.au/listen/live/radionational")



def ABC_triple_j_LIVE():
    return Radio3(browser,0,"https://www.abc.net.au/listen/live/triplej")

def ABC_triple_j_QLD():
    return Radio3(browser,1,"https://www.abc.net.au/listen/live/triplej")

def ABC_triple_j_WA():
    return Radio3(browser,2,"https://www.abc.net.au/listen/live/triplej")

def ABC_triple_j_SA():
    return Radio3(browser,3,"https://www.abc.net.au/listen/live/triplej")

def ABC_triple_j_NT():
    return Radio3(browser,4,"https://www.abc.net.au/listen/live/triplej")

def ABC_triple_j_Unearthed():
    return Radio1(browser,7,"https://www.abc.net.au/triplej/live/unearthed")
    
def ABC_triple_j_Hottest():
    return Radio1(browser,7,"https://www.abc.net.au/triplej/live/triplejhottest")


def ABC_Double_j_LIVE():
    return Radio3(browser,0,"https://www.abc.net.au/listen/live/doublej")

def ABC_Double_j_QLD():
    return Radio3(browser,1,"https://www.abc.net.au/listen/live/doublej")

def ABC_Double_j_WA():
    return Radio3(browser,2,"https://www.abc.net.au/listen/live/doublej")

def ABC_Double_j_SA():
    return Radio3(browser,3,"https://www.abc.net.au/listen/live/doublej")

def ABC_Double_j_NT():
    return Radio3(browser,4,"https://www.abc.net.au/listen/live/doublej")
    
    
def ABC_Classic_LIVE():
    return Radio3(browser,0,"https://www.abc.net.au/listen/live/classic")

def ABC_Classic_QLD():
    return Radio3(browser,1,"https://www.abc.net.au/listen/live/classic")

def ABC_Classic_WA():
    return Radio3(browser,2,"https://www.abc.net.au/listen/live/classic")

def ABC_Classic_SA():
    return Radio3(browser,3,"https://www.abc.net.au/listen/live/classic")

def ABC_Classic_NT():
    return Radio3(browser,4,"https://www.abc.net.au/listen/live/classic")


def ABC_Classic2():
    return Radio1(browser,7,"https://www.abc.net.au/listen/live/classic2")
    
def ABC_Jazz():
    return Radio1(browser,7,"https://www.abc.net.au/listen/live/jazz")
    
def ABC_Country():
    return Radio5(browser,3,"https://www.abc.net.au/listen/live/country")

def ABC_Kids_listen():
    return Radio6(browser,"https://www.abc.net.au/listenlive/kidslisten")
    
def ABC_Radio_AUSTRALIA():
    return Radio5(browser,3,"https://www.abc.net.au/pacific/live")

def ABC_SPORT():
    return Radio7(browser,0,"https://www.abc.net.au/news/sport/audio")

def ABC_SPORT_EXTRA():
    return Radio7(browser,1,"https://www.abc.net.au/news/sport/audio")

def ABC_CRICKET():
    return Radio7(browser,2,"https://www.abc.net.au/news/sport/audio")
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
